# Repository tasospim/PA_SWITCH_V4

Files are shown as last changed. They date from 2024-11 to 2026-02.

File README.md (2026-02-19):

Home_Safe_9

Almost everything in our life starts with a story. So here too behind this work, there is a story. 

In 1993, my professional journey into the world of security systems began. 
An era completely different from today where security systems were in their first stage and the technology 
they used was comparable to that era (Photo Bellow)

VINTAGE_Alarm_3

Over the years, these also followed the rapid development of technology, reaching today. 
Unfortunately, the safety of people had the opposite route than the technology had.
Since 2007 I have been noticing some burglary incidents in the news where thieves broke into homes while the residents were inside with unforeseen consequences for the residents as well as the thieves. In many of these cases the residents were elderly. 

The security systems of that era start to become complex and difficult to use for these people but also for those who are not familiar with the technology. Also, many of them, at least in my country, could not afford it to acquire such a security system. 

This is how the idea was born to create a security system that will have as a prerequisite the ease of use but also the low cost, so that they have the possibility to install it in their home. 

Another important factor for this project is the technician who will undertake to install this security system, and for me personally it is the most important. Because he is the one who will give life to this work and the one who will fulfill all of it chain from theory to practice. 
For this reason, another condition for me was the ease of use and installation of the system, as well as respect for the way of work that the installer will need to implement. 

This project was first created in 2011 and after some improvements it reached the current level. My purpose as the creator of this project is to make this product available and reach the homes of people who need it. 

Note: The project as presented has already been tested and installed on many of my friends and relatives from 2011 until today Febraury 2026. Also it is a project that I have loved, it is alive and constantly evolving following new technologies. I will try my best to support this project by giving all necessary information for my work. 

Thanks for taking the time to read these words.
With regards and love: 

Poimenidis Anastasios

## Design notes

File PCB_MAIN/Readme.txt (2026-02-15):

This is the Final PCB. That PCB was made with EasyEda Pro Design tool.
You will find the Project files inside the ziped folder -> ProPrj_PA_SWITCH_V4_2026-02-15.epro
You can import this file as project, from your local PC ( You can run EasyEda pro Localy on PC )
Or you can see the project files online:  https://oshwlab.com/tasospim/pa_switch_v4

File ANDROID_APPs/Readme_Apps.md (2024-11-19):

The Application PA_SW_Mon_V4.apk , is used to Monitoring the System by the User.

The Application PA_SW_Prog_V4.apk is used by the Installer to configure and program the System.

The Application PA_SWITCH_DIALER.apk is used by the Installer to program the phone numbers
in case of System Alarm ( Calling 1-8 Phone Numbers, Using PSTN Land Line )

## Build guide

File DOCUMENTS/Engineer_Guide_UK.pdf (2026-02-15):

MAIN PANEL PROGRAMMING

In addition to the mobile application for programming the board, the Uart port of the processor can also be used. Which is configured as follows: Baud Rate 9600, Data 8-bits, No Parity, 1 Stop Bit. The pins of the Uart of the processor are indicated on the PCB board in the connector where the Bluetooth Module is placed. And the correct correspondence is as follows:
MCU Uart Pins | Bluetooth Module Pins labeled on PCB
RX → | TX → external Serial Device
TX → | RX → external Serial Device
GND → | -
3.3V → | +
Thus it can be programmed via PC → USB to → Serial Converter or with any other external serial device. The logic of data exchange from and to the processor is as follows: The external serial device sends the programming data to the processor and the processor must respond for the correct or incorrect reception of the programming data.
The sequence of programming data sent from the PC (the other serial device) to the processor
and vice versa is as follows.
Request from external serial device to write new data:
The external serial device sends a total of 20-Bytes, including the new data we want to program and some others that define a communication protocol..
Processor response.
On the other hand, the processor will check the data it has received and respond accordingly by sending a total of 11-Bytes, The format of the response is defined by a communication protocol. NOTE
You can contact me to give you the full Format of the communication protocol.

PROGRAMMING FOR MOBILE DEVICES WITH IOS

Based on the protocol I mentioned before and using an application like Uart Terminal software (such as Bluetooth Terminal → IOS app) we are able to program the board.

| IMPORTANT NOTE
For the correct operation of the processor, we must program the User Configuration Option Byte and specifically the VDDA_MONITOR so that it is unchecked.

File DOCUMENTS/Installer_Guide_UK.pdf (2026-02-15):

INSTALLER GUIDE

MAIN PANEL CONNECTIONS

All Main panel connections are shown below. Terminal Inputs - Outputs and on board external modules.

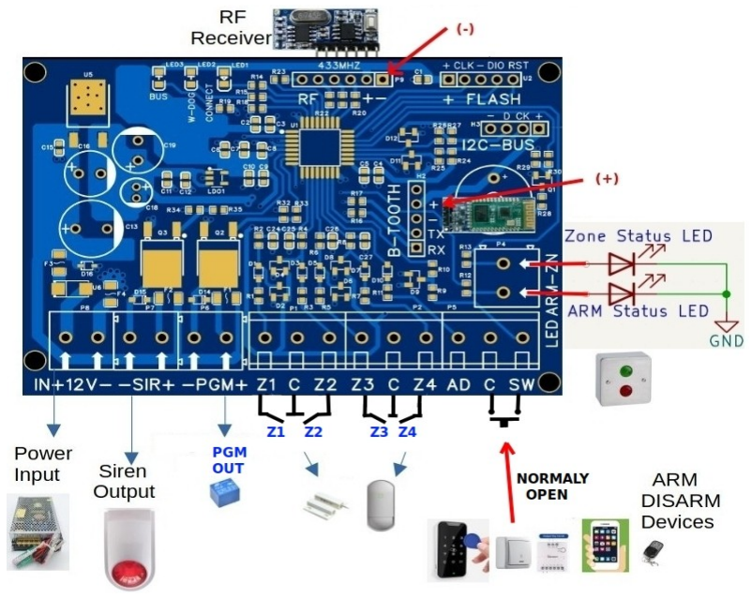
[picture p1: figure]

Terminal Inputs and Outputs
1. System Power Supply Input ( IN+12V- ) .

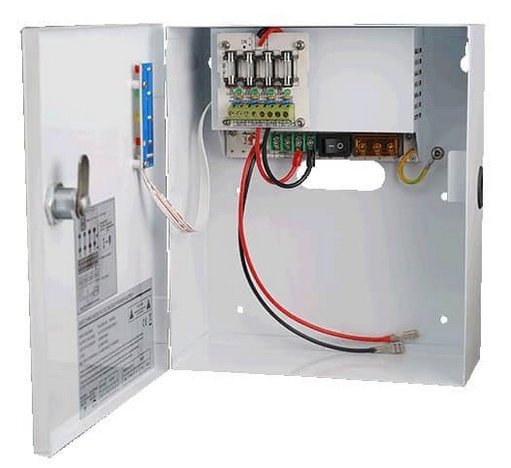
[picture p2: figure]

The system require 12V/2A power supply. The voltage limits are 10.5V – 15V and the current must be at minimum 2A.
It is a good idea to also have a backup battery circuit (as shown in the image above right) , so that the alarm will work in the event of a power loss .The power supply cabinet also could be used as enclosure box for the Main Panel Board ( as DIY job ).
2) Siren Output ( -SIR+ ).
The board provide 12V/1A on that Output for an indoor or outdoor Siren
3) PGM Output ( -PGM+ ).
The board provide 12V/100ma on that Output. This output is programmable and triggered in some system events.
4) Zone Inputs ( Z1 – C – Z2 + Z3 – C – Z4 ).
The Sensor Inputs for the zone terminals, must be a dry contact.
Those inputs are Normally Closed ( NC )
5) Alarm activation and deactivation input ( SW – C ).
This input must be Dry contact and Normally Open (NO). For the command to be accepted, the contact must be closed for at least 700msec and then return to the previous Normally Open state.
6) Arm Status and Zone Status LED Outputs ( ARM – ZN ).
When these outputs are enabled, they can drive a LED at 3 volt and a maximum of 15 mA.

ON BOARD EXTERNAL MODULES

1) RF433MHZ Receiver Module.
By installing this receiver, we are given the opportunity to use Remote Controls to
operate the alarm.
2) BlueTooth Module ( HC05 or HC06 ).
By installing this Module, the user is given the opportunity to use the alarm from the mobile application (PA_SW_Mon_V4.apk). The installer can also program the panel with
the PA_SW_Prog_V4.apk application.

NOTE: Attention should be paid to the correct polarity of the Module placement.
As shown in the picture above.

MAIN PANEL PROGRAMMING
To program the panel, you need to:
1) Place the BlueTooth Module on the panel and
2) Install the PA_SW_Prog_V4.apk application on your mobile phone.
Attention: The application is only for Android phones. It is also possible to use Iphone, but the procedure is more specific and described in the file Engineer_Guide.pdf

Connecting the mobile phone to the panel:
1) After downloading the PA_SW_Prg_V4.apk application, you should install it on your mobile.
2) The Bluetooth of the mobile should be activated
3) You should pair your mobile with the BlueTooth Module(HC-05 or HC-06). On the mobile, go to Settings → Bluetooth → More Settings → Available Devices.

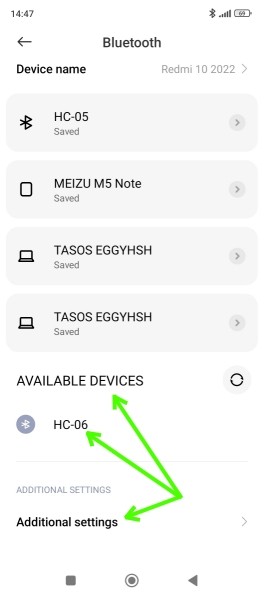
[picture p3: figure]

There you should see the HC-05 or HC-06 device. You should pair your mobile with the Bluetooth Module(HC-05 or HC-06). Select the device as shown on the left icon and enter the
code 1234 to Register the device, as shown on the
right icon
If you have already done this on your mobile for this particular device, then skip this step.

Note: The setup path followed is for a Xiaomi device. It may be different for your mobile.

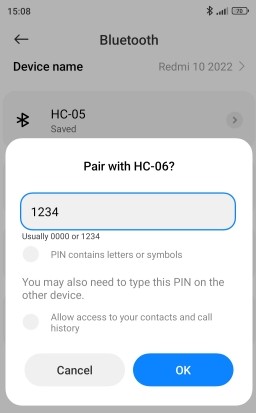
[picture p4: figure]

4) Run the Application PA_SW_Prg_V4. You should see a screen as shown in the image-1 below.
5) Press the icon that shows the bluetooth.
And there from the list that will appear, select the device you paired and wait for the mobile to connect to the panel. If everything has gone well, the programming data fields should be colored, as shown in image-2 below.
If something goes wrong, then a message will appear as shown in image-3 below.
Note: On initial connection, it takes some time for the board to synchronize with the mobile. At this point the mobile may give you this message. If this happens, then you should select → Wait.

Image-1 | Image-2 | Image-3 | Image-4

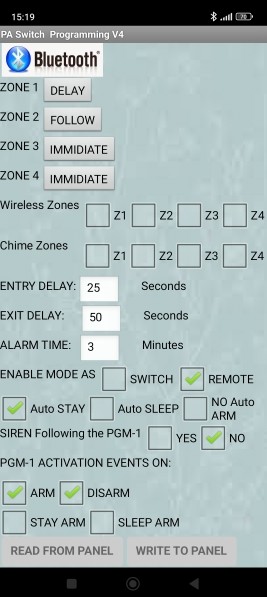
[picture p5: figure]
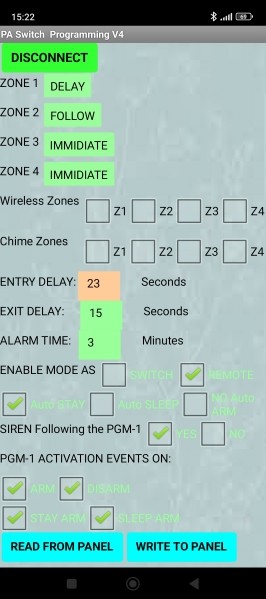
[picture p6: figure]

Programming of the main panel features:

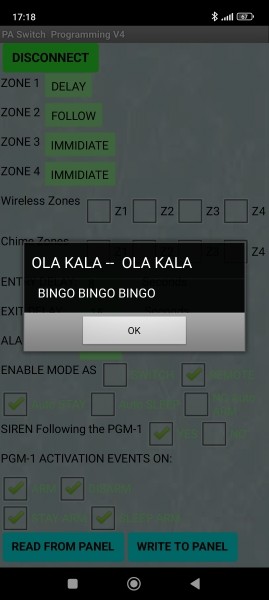
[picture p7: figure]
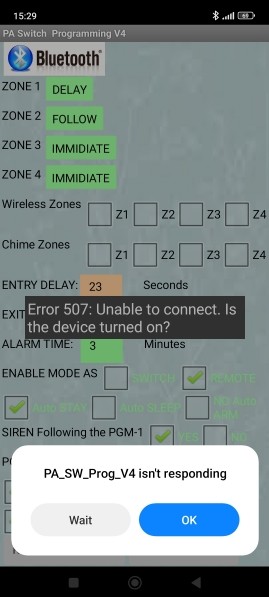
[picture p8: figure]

Before we try to change the data in the Main Panel, it is a good idea to first read the existing data. This is to ensure that the board is communicating properly with the mobile phone and that the data is synchronized. To do this, we press the button → Read From Panel. If the data is read successfully, then the message in image-4 will be displayed. From this point on, the panel data is synchronized with the application data. For this reason, the data it is marked with the green color. If we change, for example, the entry time to a value of 23 from 25, which is the initial value, then this field will change color and become orange, as shown in image-2. In order to be able to update the panel with the changes we have made, then we press the → Write To Panel button. If the data is successfully written to the panel, then the message in image-4 will appear.

Explanation of the programming data values:
1) Zone 1 – Zone 4. Here we define the type of each zone.
2) Wireless Zones Z1 – Z4. For future use.
3) Chime Zones Z1 – Z4. We define which zone(s) will generate sound on the central panel's Buzzer.
4) Entry Delay. The entry delay time in seconds.
5) Exit Delay. The exit delay time in seconds.
6) Alarm Time. Siren time in minutes, in case Alarm of the system.
7) Enable Mode. It should be enabled the option → Remote.
The option → Switch, comes from an older version of the system.
8) Auto Arm. If the entrance door is not opened during the exit delay time, then we can choose in which state the alarm will arm. It can be set to arm as Stay - Sleep - No Auto Arm (Regular Arm). This is very convenient because the user does not need to choose how to arm the alarm, nor does he need to Bypass the zones. So by using only 1 Push-Button the user can arm when leaving the house in Regular Arm mode, while when not leaving the house in
Stay or Sleep mode.
9) Siren Follow PGM. With this option it is possible for the siren to be activated when the programmable PGM is activated too. This way the user can be given confirmation that he has armed or disarmed the alarm (Different sound in each case). This is very convenient when the user uses Remote Control to activate the alarm and is not inside the house, so that he has audible confirmation from the central panel.
10) PGM Activation Event On. With this option we can choose which system events will trigger the PGM output.

Monitoring the system using mobile Application:
To do this, the procedure as described above in the section → Connecting the mobile phone to the panel must be followed, with the difference that the corresponding application for the user is → PA_SW_Mon_V4.apk and the application screens before and after connecting to the panel are those shown in images-5-6-7.
Image-5 | Image-6 | Image-7

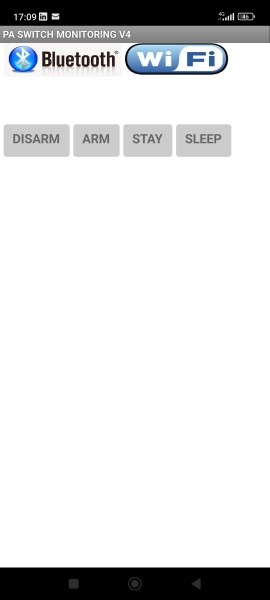
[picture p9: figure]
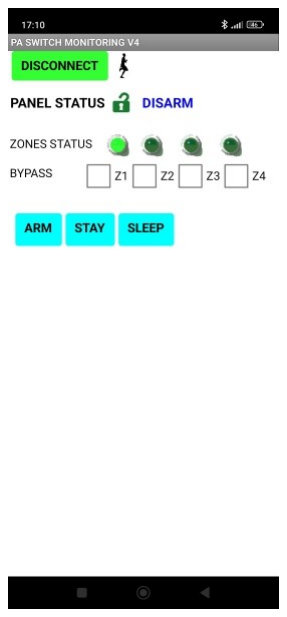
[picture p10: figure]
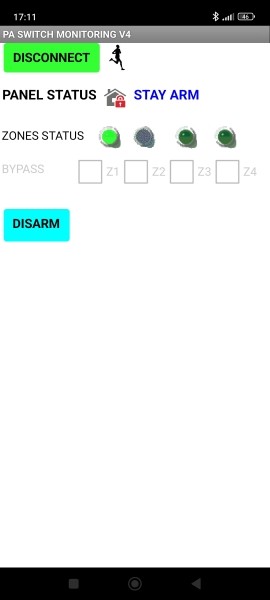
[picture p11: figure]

In this application, the user can choose to Bypass simply by clicking the corresponding zone Z1-Z4. It is also possible to see the current zone status. The status of the zones is determined by the LED color, according to the table below.

LED Color | Light Green | Dark Green | Grey | Red
Zone Status | Zone Open | Zone Closed | Zone Bypassed | Zone in Alarm

The user can choose to activate the alarm in any desired Mode → Arm – Stay – Sleep. In Stay and Sleep mode, the zones that are FOLLOW are automatically disabled (Bypassed). whereas only in Sleep mode, the zones that are DELAY are automatically converted to IMMEDIATE (Instant).
Note: The runner icon shown on the application, indicate the active communication between the Main Panel and the App. Every runner step means packet of data exchange.

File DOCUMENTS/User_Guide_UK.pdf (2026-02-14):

USER GUIDE

SYSTEM INDICATIONS
The system indications are displayed on 2 LEDs. The Arm LED and the Zone Status LED. The way these LEDs are flashing, indicates the status of the zones and the system in general. The table below specifies the full function of these LEDs.
LED Status | OFF | ON | Blinking Fast | Blinking Slow
Arm LED | Disarmed | Regular Arm | Sleep Arm | Stay Arm
Zone LED | Zone(s) Open | All Zones Closed | System In Alarm | --------

The location of these LEDs is determined by the user's control device and by the installation method chosen by the installer.

SYSTEM CONTROL DEVICES
The user can choose any of the following devices.
1. Remote Control.
The following keys are exist on Remote Control: A-B-C-D . The function of those keys are.
Α – Regular Arm. B – Disarm
C - Sleep Arm D – Force Panic Alarm
The user can have audible confirmation when arming or disarming the system. And in consultation with the installer, can choose the specific confirmation event.
2. Push Button.

The easiest way for the user to operate the system is a simple Push-Button switch. Each time the switch is pressed, the system status changes from Armed to Disarmed and vice versa. The corresponding LEDs indicate the current system status (According to the table above).

If the user does not open the entrance door to leave the house during the exit time, then the system enters in SLEEP mode. That is, the internal motion sensors are deactivated and the entrance door becomes immediate (without time). However, if the user opens the door, then it means that he will leave the house. In this case, the system arms in Regular Arm mode.

3. Stand Alone Access Control.

In this case the user can use the keyboard by entering a code, or use a contactless card (RFID).

4. Mobile App.

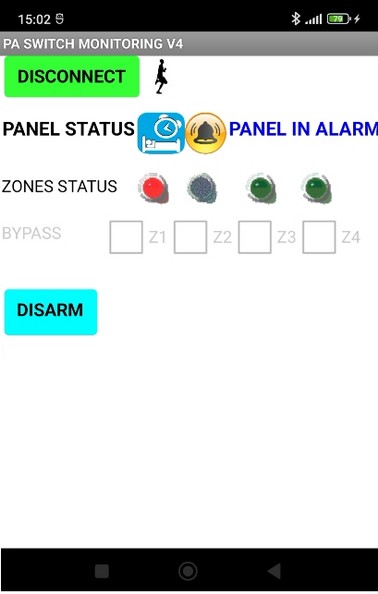
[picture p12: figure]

With this application the user can do all the functions of the system. Regular Arm – Stay Arm – Sleep Arm – Disarm - Zone Bypass. Also he can see the status of all the zones.

5. SonOff

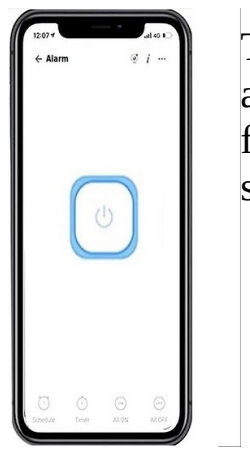
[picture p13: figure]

The user can arm or disarm the alarm through this application. Either locally from the home wifi or remotely from any place. This Application is corresponding to a specific SonOff that the installer has used.

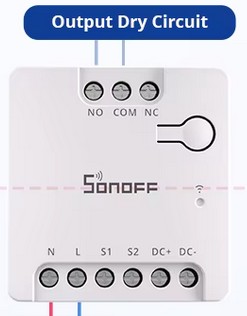
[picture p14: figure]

NOTE
All these devices can be used simultaneously. That means, one user can use the Push-Button and another user can use the Remote control, or any other device.
